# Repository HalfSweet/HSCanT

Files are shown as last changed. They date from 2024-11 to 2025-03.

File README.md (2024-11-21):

# HSCanT

HSCanT 是一款USB转4路CAN FD工具，基于HPM5321芯片设计。

## 特性

- 支持4路CAN FD通道
- 每路CAN FD通道支持最高8Mbit/s的数据传输速率
- 支持上位机配置可选的120Ω终端电阻
- 每路通道均支持独立的TX、RX状态全彩LED指示
- 支持最高±58V的过压保护

## 致谢

感谢[RCSN](https://github.com/RCSN)大佬提供的思路，以及该项目的上下位机软件支持。

- 上位机：<https://github.com/RCSN/cangaroo_hpmicro_canfd_analyzer>
- 下位机：<https://github.com/RCSN/hpm_sdk_extra/tree/main/demos/cangaroo_hpmicro>

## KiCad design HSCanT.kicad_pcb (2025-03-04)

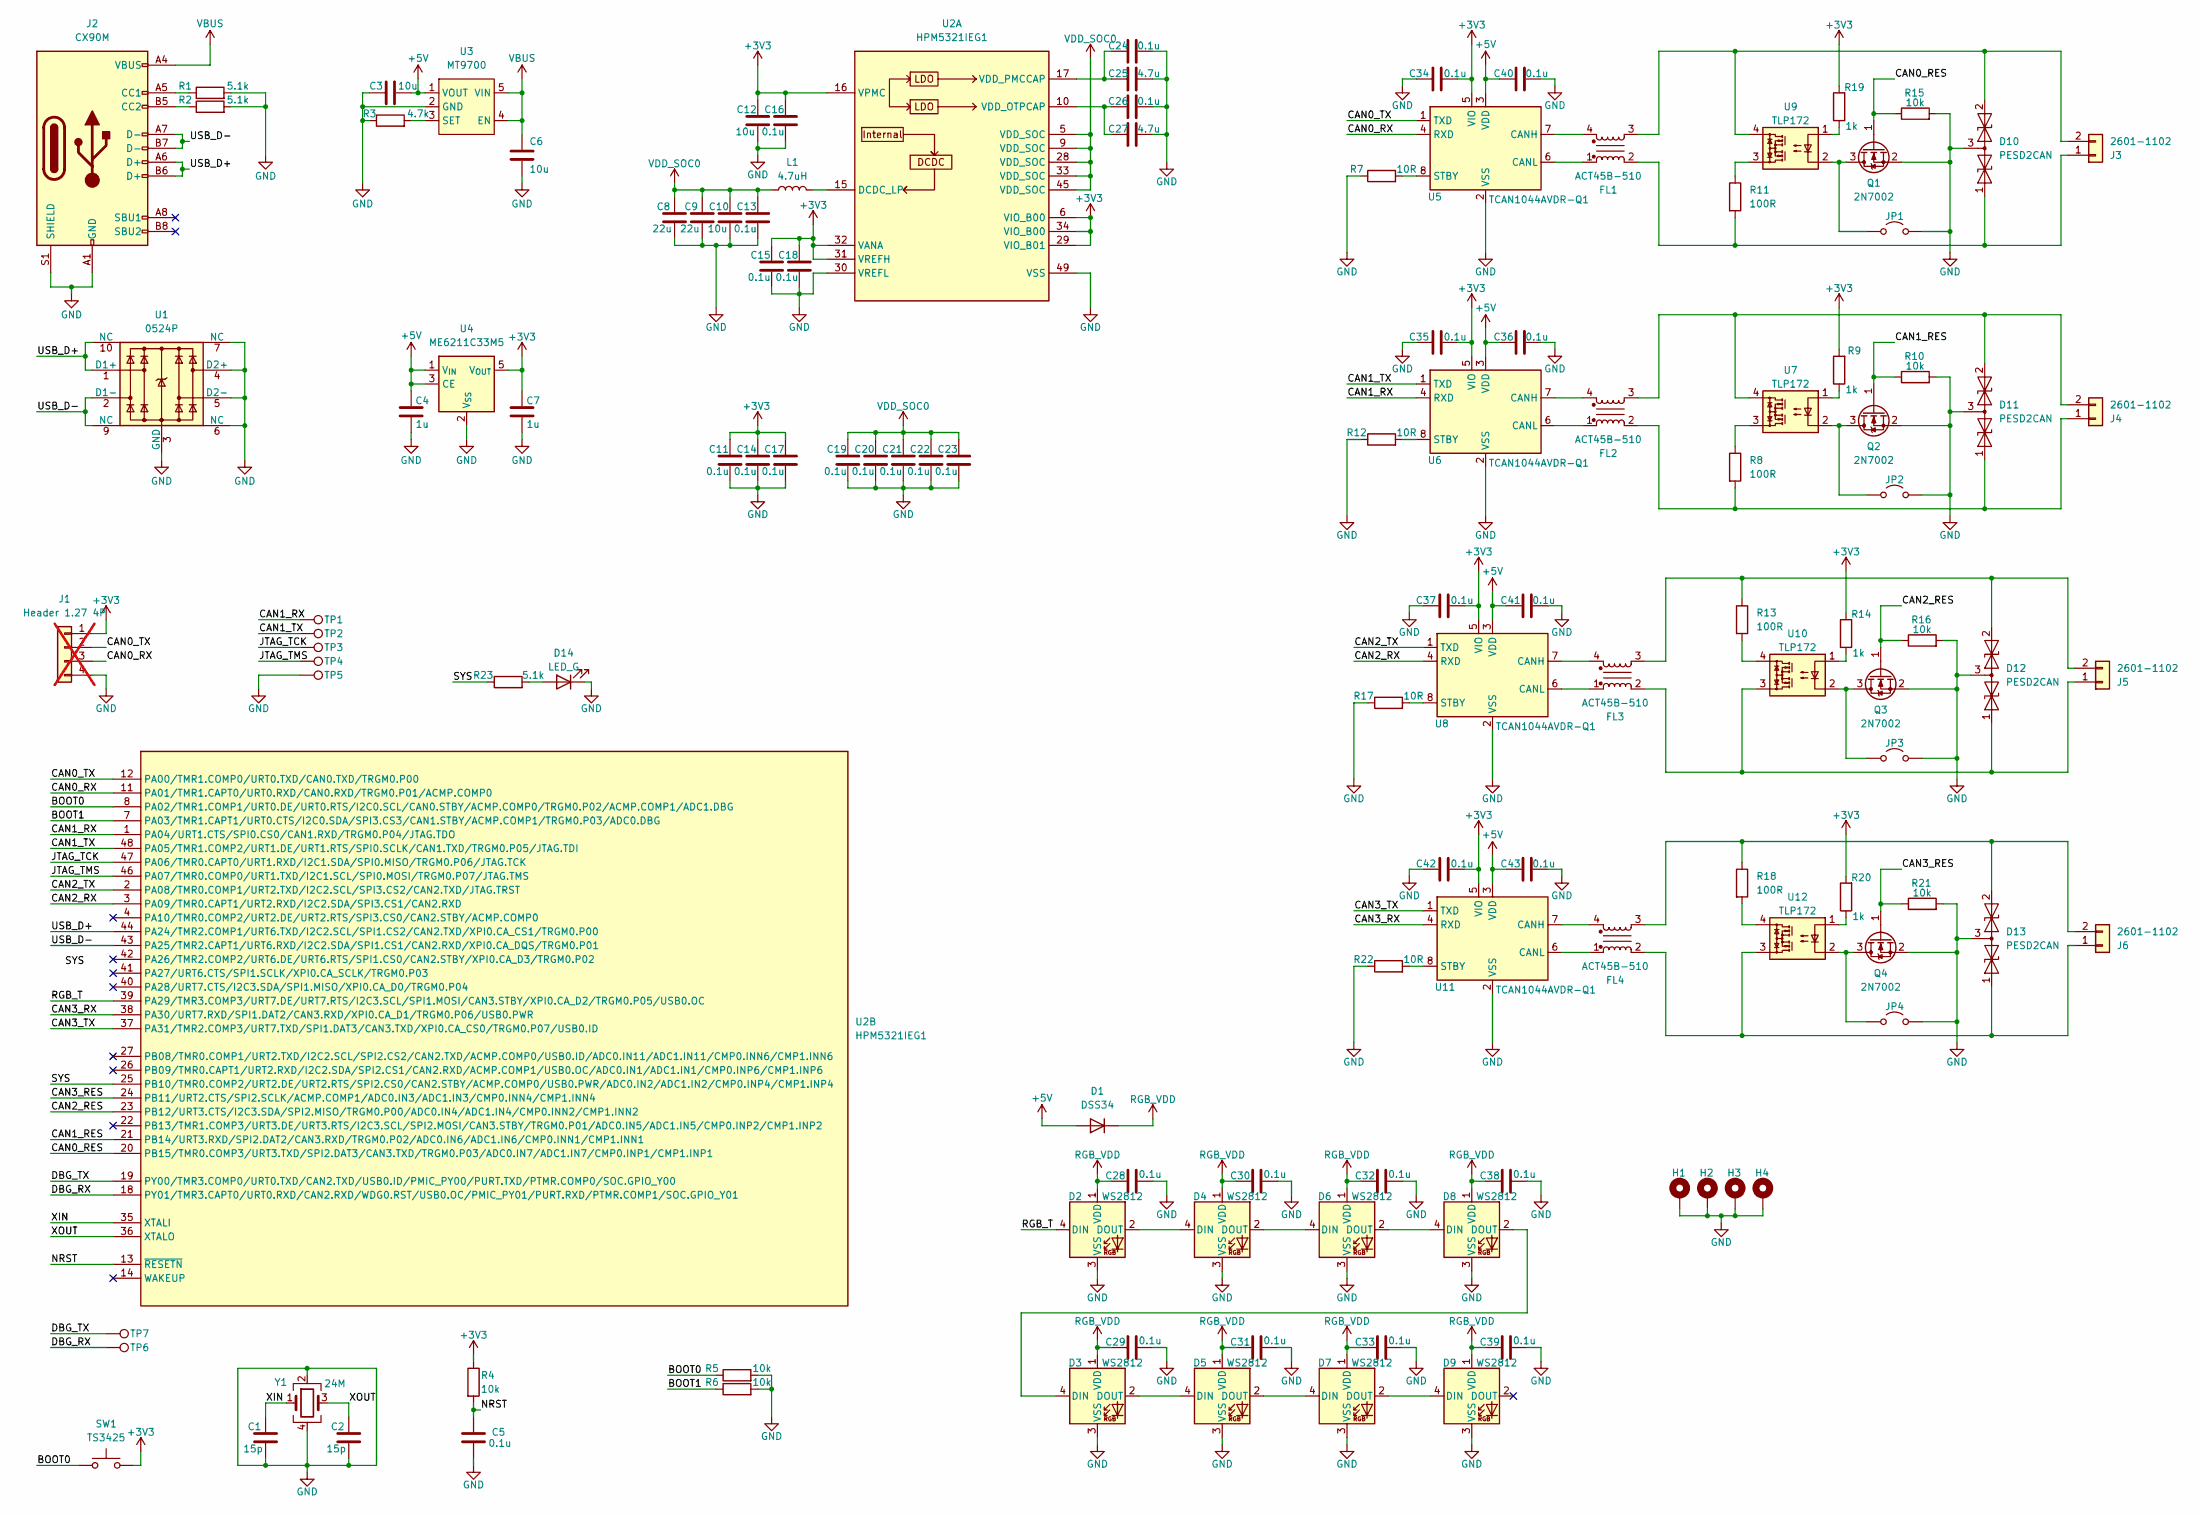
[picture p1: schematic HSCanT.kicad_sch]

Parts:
C1, C2: 15p; C_0402_1005Metric
C3, C6: 10u; C_0603_1608Metric
C4, C7: 1u; C_0402_1005Metric
C5, C11, C13, C14, C15, C16, C17, C18, C19, C20, C21, C22, C23, C24, C26, C28, C29, C30, C31, C32, C33, C34, C35, C36, C37, C38, C39, C40, C41, C42, C43: 0.1u; C_0402_1005Metric
C8, C9: 22u; C_0402_1005Metric
C10, C12: 10u; C_0402_1005Metric
C25, C27: 4.7u; C_0402_1005Metric
D1: DSS34; D_SOD-123
D2, D3, D4, D5, D6, D7, D8, D9: WS2812; LED_WS2812_0807
D10, D11, D12, D13: PESD2CAN; SOT-23
D14: LED_G; LED_0603_1608Metric
FL1, FL2, FL3, FL4: ACT45B-510; L_CommonModeChoke_Coilcraft_1812CAN
H1, H2, H3, H4: MountingHole_Pad; MountingHole_2.2mm_M2_Pad_TopBottom
J1: Header 1.27 4P; PinHeader_1x04_P1.27mm_Vertical; not fitted
J2: CX90M; USB-C-SMD_CX90M-16P
J3, J4, J5, J6: 2601-1102; WAGO-2601-1102
JP1, JP2, JP3, JP4: Jumper_2_Open; SolderJumper-2_P1.3mm_Open_RoundedPad1.0x1.5mm
L1: 4.7uH; L_1008_2520Metric
Q1, Q2, Q3, Q4: 2N7002; Diodes_DFN1006-3
R1, R2, R23: 5.1k; R_0402_1005Metric
R3: 4.7k; R_0402_1005Metric
R4, R5, R6, R10, R15, R16, R21: 10k; R_0402_1005Metric
R7, R12, R17, R22: 10R; R_0402_1005Metric
R8, R11, R13, R18: 100R; R_1206_3216Metric
R9, R14, R19, R20: 1k; R_0402_1005Metric
SW1: TS3425; SW_SPST_PTS810
TP1, TP2, TP3, TP4, TP5, TP6, TP7: TestPoint; TestPoint_Pad_D1.0mm
U1: 0524P; USON-10_2.5x1.0mm_P0.5mm
U2: HPM5321IEG1; QFN-48-1EP_6x6mm_P0.4mm_EP4.2x4.2mm
U3: MT9700; SOT-23-5
U4: ME6211C33M5; SOT-23-5
U5, U6, U8, U11: TCAN1044AVDR-Q1; DFN-8-1EP_3x3mm_P0.65mm_EP1.55x2.4mm
U7, U9, U10, U12: TLP172; SOP-4_3.8x4.1mm_P2.54mm
Y1: 24M; Crystal_SMD_2016-4Pin_2.0x1.6mm

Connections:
+3V3: C7.1, C11.1, C12.1, C14.1, C15.1, C16.1, C17.1, C18.1, C34.2, C35.2, C37.2, C42.2, J1.1, R4.1, R9.2, R14.2, R19.2, R20.2, SW1.2, U2.6 (VIO_B00), U2.16 (VPMC), U2.29 (VIO_B01), U2.31 (VREFH), U2.32 (VANA), U2.34 (VIO_B00), U4.5 (V_{OUT}), U5.5 (VIO), U6.5 (VIO), U8.5 (VIO), U11.5 (VIO)
+5V: C3.2, C4.1, C36.1, C40.1, C41.1, C43.1, D1.2 (A), U3.1 (VOUT), U4.1 (V_{IN}), U4.3 (CE), U5.3 (VDD), U6.3 (VDD), U8.3 (VDD), U11.3 (VDD)
/BOOT0: R5.1, SW1.1, U2.8 (PA02/TMR1.COMP1/URT0.DE/URT0.RTS/I2C0.S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)
/BOOT1: R6.1, U2.7 (PA03/TMR1.CAPT1/URT0.CTS/I2C0.SDA/SPI3.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)
/CAN0_RES: Q1.1 (G), R15.1, U2.20 (PB15/TMR0.COMP3/URT3.TXD/SPI2.DAT3/CAN3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)
/CAN0_RX: J1.3, U2.11 (PA01/TMR1.CAPT0/URT0.RXD/CAN0.RXD/TRGM0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), U5.4 (RXD)
/CAN0_TX: J1.2, U2.12 (PA00/TMR1.COMP0/URT0.TXD/CAN0.TXD/TRGM0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), U5.1 (TXD)
/CAN1_RES: Q2.1 (G), R10.1, U2.21 (PB14/URT3.RXD/SPI2.DAT2/CAN3.RXD/TRGM0.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)
/CAN1_RX: TP1.1, U2.1 (PA04/URT1.CTS/SPI0.CS0/CAN1.RXD/TRGM0.P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), U6.4 (RXD)
/CAN1_TX: TP2.1, U2.48 (PA05/TMR1.COMP2/URT1.DE/URT1.RTS/SPI0.S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), U6.1 (TXD)
/CAN2_RES: Q3.1 (G), R16.1, U2.23 (PB12/URT3.CTS/I2C3.SDA/SPI2.MISO/TRGM0.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)
/CAN2_RX: U2.3 (PA09/TMR0.CAPT1/URT2.RXD/I2C2.SDA/SPI3.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), U8.4 (RXD)
/CAN2_TX: U2.2 (PA08/TMR0.COMP1/URT2.TXD/I2C2.SCL/SPI3.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), U8.1 (TXD)
/CAN3_RES: Q4.1 (G), R21.1, U2.24 (PB11/URT2.CTS/SPI2.SCLK/ACMP.COMP1/ADC0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)
/CAN3_RX: U2.38 (PA30/URT7.RXD/SPI1.DAT2/CAN3.RXD/XPI0.C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), U11.4 (RXD)
/CAN3_TX: U2.37 (PA31/TMR2.COMP3/URT7.TXD/SPI1.DAT3/CAN3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), U11.1 (TXD)
/DBG_RX: TP6.1, U2.18 (PY01/TMR3.CAPT0/URT0.RXD/CAN2.RXD/WDG0.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)
/DBG_TX: TP7.1, U2.19 (PY00/TMR3.COMP0/URT0.TXD/CAN2.TXD/USB0.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)
/JTAG_TCK: TP3.1, U2.47 (PA06/TMR0.CAPT0/URT1.RXD/I2C1.SDA/SPI0.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)
/JTAG_TMS: TP4.1, U2.46 (PA07/TMR0.COMP0/URT1.TXD/I2C1.SCL/SPI0.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)
/NRST: C5.1, R4.2, U2.13 (~RESETN)
/RGB_T: D2.4 (DIN), U2.39 (PA29/TMR3.COMP3/URT7.DE/URT7.RTS/I2C3.S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)
/SYS: R23.1, U2.25 (PB10/TMR0.COMP2/URT2.DE/URT2.RTS/SPI2.C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)
/USB_D+: J2.A6 (D+), J2.B6 (D+), U1.1 (D1+), U1.10 (NC), U2.44 (PA24/TMR2.COMP1/URT6.TXD/I2C2.SCL/SPI1.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)
/USB_D-: J2.A7 (D-), J2.B7 (D-), U1.2 (D1-), U1.9 (NC), U2.43 (PA25/TMR2.CAPT1/URT6.RXD/I2C2.SDA/SPI1.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)
/XIN: C1.1, U2.35 (XTALI), Y1.1
/XOUT: C2.1, U2.36 (XTALO), Y1.3
GND: C1.2, C2.2, C3.1, C4.2, C5.2, C6.2, C7.2, C8.2, C9.2, C10.2, C11.2, C12.2, C13.2, C14.2, C15.2, C16.2, C17.2, C18.2, C19.2, C20.2, C21.2, C22.2, C23.2, C24.2, C25.2, C26.2, C27.2, C28.2, C29.2, C30.2, C31.2, C32.2, C33.2, C34.1, C35.1, C36.2, C37.1, C38.2, C39.2, C40.2, C41.2, C42.1, C43.2, D2.3 (VSS), D3.3 (VSS), D4.3 (VSS), D5.3 (VSS), D6.3 (VSS), D7.3 (VSS), D8.3 (VSS), D9.3 (VSS), D10.3 (common), D11.3 (common), D12.3 (common), D13.3 (common), D14.1 (K), H1.1, H2.1, H3.1, H4.1, J1.4, J2.A1 (GND), J2.A12 (GND), J2.B1 (GND), J2.B12 (GND), J2.S1 (SHIELD), JP1.2 (B), JP2.2 (B), JP3.2 (B), JP4.2 (B), Q1.2 (S), Q2.2 (S), Q3.2 (S), Q4.2 (S), R1.2, R2.2, R3.1, R5.2, R6.2, R7.1, R10.2, R12.1, R15.2, R16.2, R17.1, R21.2, R22.1, TP5.1, U1.3 (GND), U1.4 (D2+), U1.5 (D2-), U1.6 (NC), U1.7 (NC), U1.8 (GND), U2.30 (VREFL), U2.49 (VSS), U3.2 (GND), U4.2 (V_{SS}), U5.2 (VSS), U5.9 (VSS), U6.2 (VSS), U6.9 (VSS), U8.2 (VSS), U8.9 (VSS), U11.2 (VSS), U11.9 (VSS), Y1.2, Y1.4
unnamed: D2.2 (DOUT), D4.4 (DIN)
unnamed: D3.4 (DIN), D8.2 (DOUT)
unnamed: D3.2 (DOUT), D5.4 (DIN)
unnamed: D4.2 (DOUT), D6.4 (DIN)
unnamed: D5.2 (DOUT), D7.4 (DIN)
unnamed: D6.2 (DOUT), D8.4 (DIN)
unnamed: D7.2 (DOUT), D9.4 (DIN)
unnamed: D10.1 (A1), FL1.2, J3.1, R11.2
unnamed: D10.2 (A2), FL1.3, J3.2, U9.4
unnamed: D11.1 (A1), FL2.2, J4.1, R8.2
unnamed: D11.2 (A2), FL2.3, J4.2, U7.4
unnamed: D12.1 (A1), FL3.2, J5.1, U10.3
unnamed: D12.2 (A2), FL3.3, J5.2, R13.1
unnamed: D13.1 (A1), FL4.2, J6.1, U12.3
unnamed: D13.2 (A2), FL4.3, J6.2, R18.1
unnamed: D14.2 (A), R23.2
unnamed: J2.A5 (CC1), R1.1
unnamed: J2.B5 (CC2), R2.1
unnamed: JP1.1 (A), Q1.3 (D), U9.2
unnamed: JP2.1 (A), Q2.3 (D), U7.2
unnamed: JP3.1 (A), Q3.3 (D), U10.2
unnamed: JP4.1 (A), Q4.3 (D), U12.2
unnamed: R8.1, U7.3
unnamed: R9.1, U7.1
unnamed: R11.1, U9.3
unnamed: R13.2, U10.4
unnamed: R14.1, U10.1
unnamed: R18.2, U12.4
unnamed: R19.1, U9.1
unnamed: R20.1, U12.1
unnamed: L1.2, U2.15 (DCDC_LP)
unnamed: C26.1, C27.1, U2.10 (VDD_OTPCAP)
unnamed: C24.1, C25.1, U2.17 (VDD_PMCCAP)
unnamed: R3.2, U3.3 (SET)
unnamed: FL1.4, U5.7 (CANH)
unnamed: FL1.1, U5.6 (CANL)
unnamed: R7.2, U5.8 (STBY)
unnamed: FL2.4, U6.7 (CANH)
unnamed: FL2.1, U6.6 (CANL)
unnamed: R12.2, U6.8 (STBY)
unnamed: FL3.4, U8.7 (CANH)
unnamed: FL3.1, U8.6 (CANL)
unnamed: R17.2, U8.8 (STBY)
unnamed: FL4.4, U11.7 (CANH)
unnamed: FL4.1, U11.6 (CANL)
unnamed: R22.2, U11.8 (STBY)
RGB_VDD: C28.1, C29.1, C30.1, C31.1, C32.1, C33.1, C38.1, C39.1, D1.1 (K), D2.1 (VDD), D3.1 (VDD), D4.1 (VDD), D5.1 (VDD), D6.1 (VDD), D7.1 (VDD), D8.1 (VDD), D9.1 (VDD)
VBUS: C6.1, J2.A4 (VBUS), J2.A9 (VBUS), J2.B4 (VBUS), J2.B9 (VBUS), U3.4 (EN), U3.5 (VIN)
VDD_SOC0: C8.1, C9.1, C10.1, C13.1, C19.1, C20.1, C21.1, C22.1, C23.1, L1.1, U2.5 (VDD_SOC), U2.9 (VDD_SOC), U2.28 (VDD_SOC), U2.33 (VDD_SOC), U2.45 (VDD_SOC)

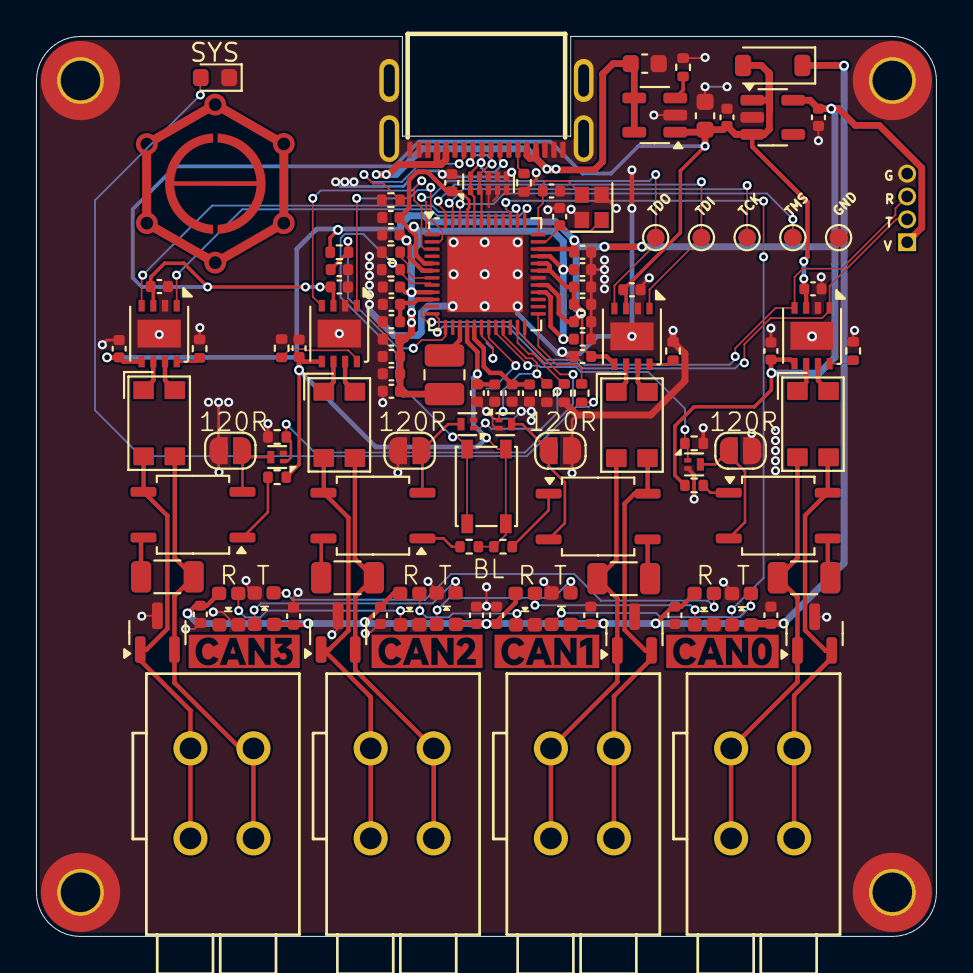
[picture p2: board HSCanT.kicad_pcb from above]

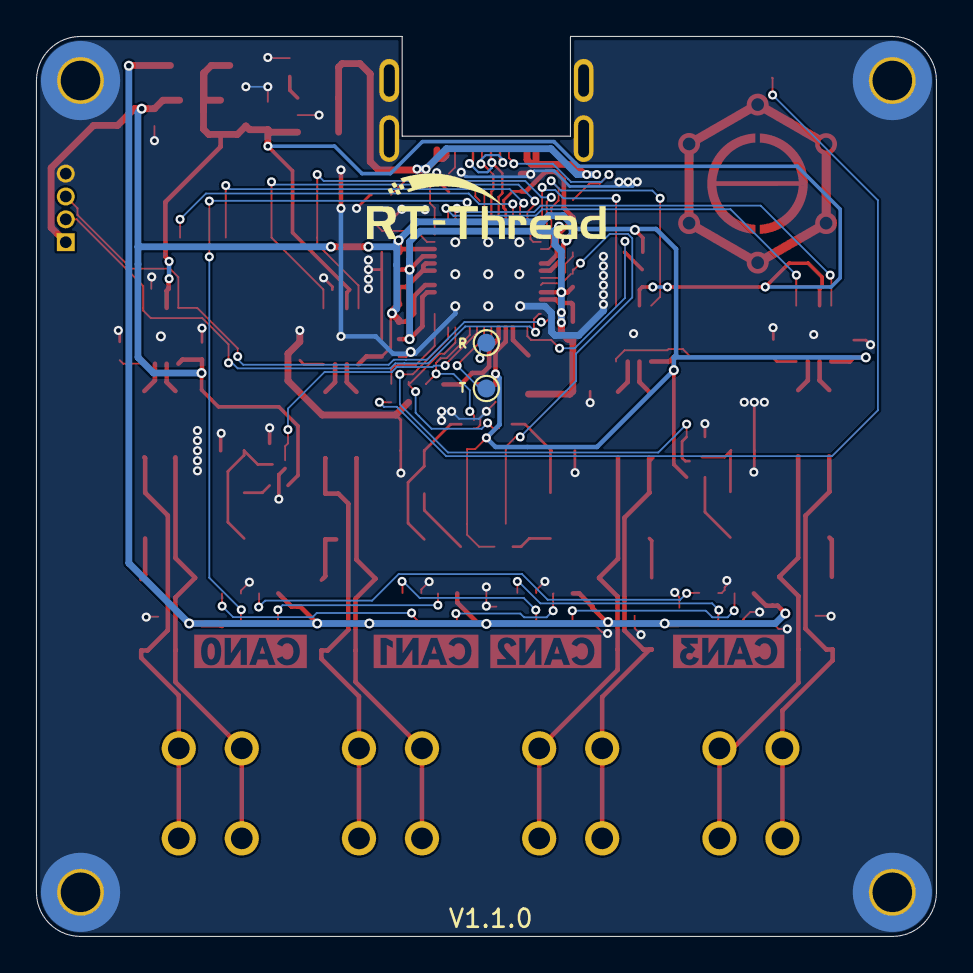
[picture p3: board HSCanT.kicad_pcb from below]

Board: 4 copper layers, 50.0 x 50.0 mm, 128 parts (2 on the bottom side), 77 nets.

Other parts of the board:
kibuzzard-6738A07D: G***; kibuzzard-6738A07D
kibuzzard-6738A057: G***; kibuzzard-6738A057
kibuzzard-6738A074: G***; kibuzzard-6738A074
kibuzzard-6738A091: G***; kibuzzard-6738A091

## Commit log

2024-11-21 update: 更新原理图和PCB
    [HSCanT.kicad_pcb, HSCanT.kicad_sch]
2025-03-04 release: v1.1.0
    [HSCanT.kicad_pcb, HSCanT.kicad_sch]

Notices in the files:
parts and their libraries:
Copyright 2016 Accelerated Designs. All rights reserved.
